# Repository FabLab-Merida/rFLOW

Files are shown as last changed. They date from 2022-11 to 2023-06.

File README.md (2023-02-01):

# rFLOW - FabLab Mérida

Proyecto made in FabLab Mérida por el cual mediante el reciclaje de una antigua plancha de vapor y algunos componentes electronicos, se ha convertido en una estación de soldadura BGA monocapa. Capaz de llegar hasta 250º, ideal para multiples tipos de pasta de estaño.

## Motivación  

La principal motivación tras este proyecto es buscar una solución económica a la creacion de PCBs y reparación de estas promoviendo la economia circular y el reciclaje de componentes y piezas.

## Materiales 

1 * Relé de 5V que soporte como miínimo 250V y 13A. <br />
1 * Termistor (vease el .ino para mas información). <br />
1 * Resistencia de la plancha de vapor. <br />
1 * Baquelita monocapa virgen. <br />
1 * ATMEGA 328p. <br />
3 * Botones Push. <br />
3 * Resistencias de 1kO. <br />
1 * Resistencia de 4.7kO. <br />
1 * Condensador de 10uF. <br />
1 * Potenciometro 10kO. <br />
1 * LCD 16*4 segmentos. <br />

## Resultados

La posibilidad de usar un amplio rango de temperatura estable ha dado lugar a múltiples aplicaciones extra, desde el anteriormente mencionada creación de PCBs pasando por facilitar soldaduras por aire manteniendo la zona caliente o secado de filamento de impresora 3D.

## Observaciones

Se necesita que el Atmega use la frecuencia de relog interna de 8MHz, para ello se necesita grabar el bootloader por uno sin los parametros de Arduino, en la bibliografía encontrará información de como hacerlo.

## Bibliografía

LiquidCrystal.h          ==> https://www.arduino.cc/reference/en/libraries/liquidcrystal/ <br />
thermistor.h             ==> https://github.com/miguel5612/ThermistorLibrary <br />
Grabar bootloader        ==> https://docs.arduino.cc/built-in-examples/arduino-isp/ArduinoToBreadboard <br />

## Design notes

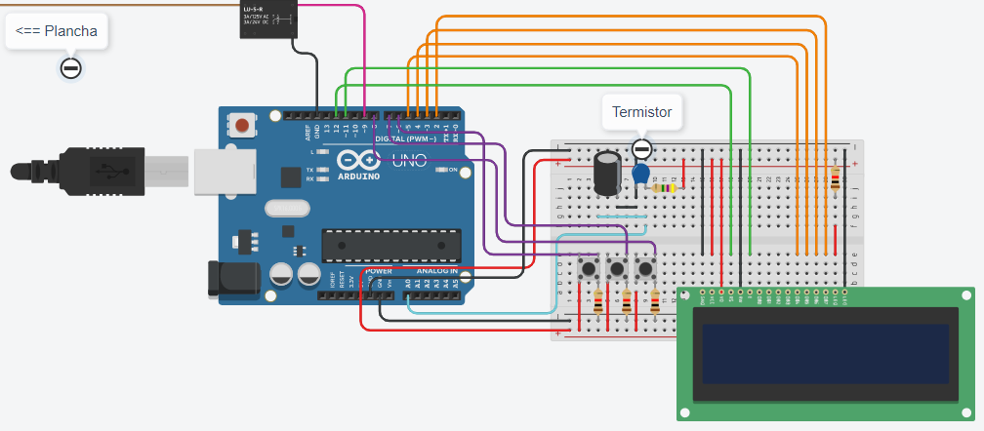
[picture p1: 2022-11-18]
Diagrama.png

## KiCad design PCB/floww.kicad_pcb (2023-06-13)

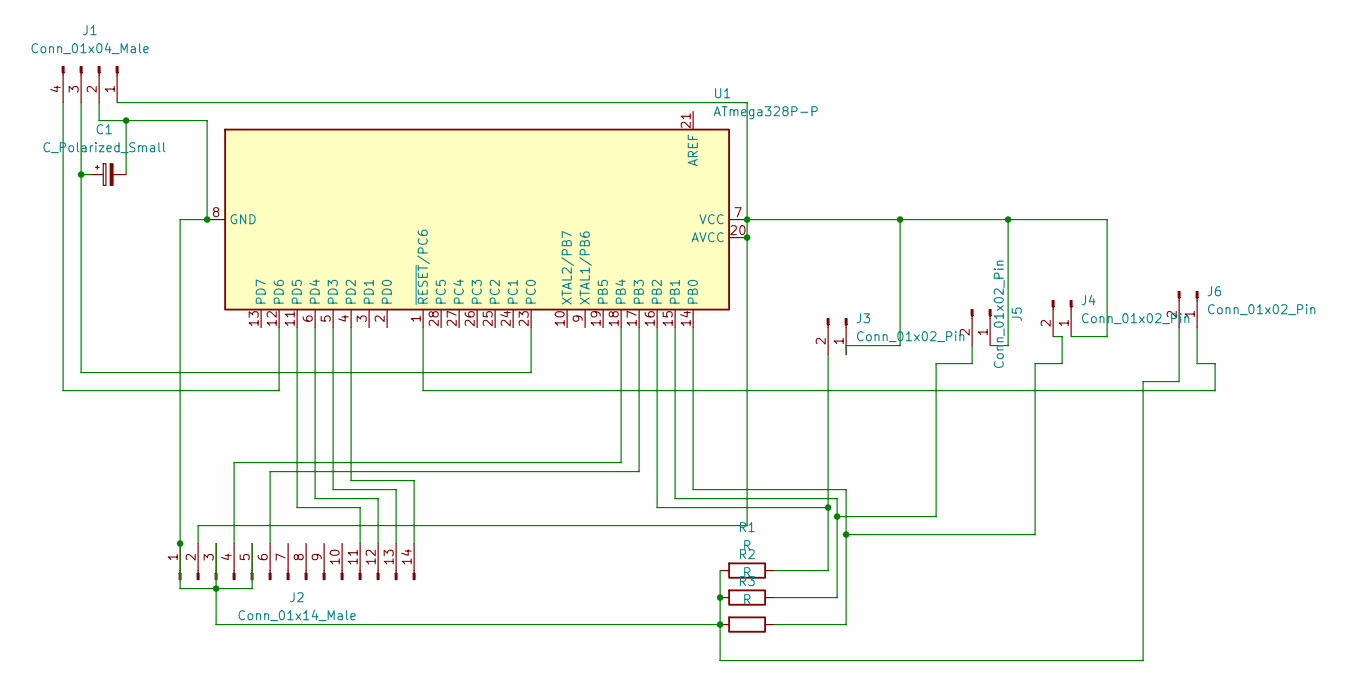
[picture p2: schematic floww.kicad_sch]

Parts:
C1: C_Polarized_Small; CP_Radial_D5.0mm_P2.50mm
J1: Conn_01x04_Male; PinHeader_1x04_P2.54mm_Vertical
J2: Conn_01x14_Male; PinHeader_1x14_P2.54mm_Vertical
J3, J4, J5, J6: Conn_01x02_Pin; PinHeader_1x02_P2.54mm_Vertical
R1, R2, R3: R; R_Axial_DIN0207_L6.3mm_D2.5mm_P10.16mm_Horizontal
U1: ATmega328P-P; DIP-28_W7.62mm

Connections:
unnamed: J1.1, J2.2, J3.1, J4.1, J5.1, U1.7 (VCC), U1.20 (AVCC)
unnamed: C1.2, J1.2, J2.1, J2.3, J2.5, J6.2, R1.2, R2.2, R3.2, U1.8 (GND), U1.22 (GND)
unnamed: C1.1, J1.3, U1.23 (PC0)
unnamed: J1.4, U1.12 (PD6)
unnamed: J2.4, U1.18 (PB4)
unnamed: J2.6, U1.17 (PB3)
unnamed: J2.11, U1.11 (PD5)
unnamed: J2.12, U1.6 (PD4)
unnamed: J2.13, U1.5 (PD3)
unnamed: J2.14, U1.4 (PD2)
unnamed: J3.2, R1.1, U1.16 (PB2)
unnamed: J4.2, R3.1, U1.14 (PB0)
unnamed: J5.2, R2.1, U1.15 (PB1)
unnamed: J6.1, U1.1 (~RESET/PC6)

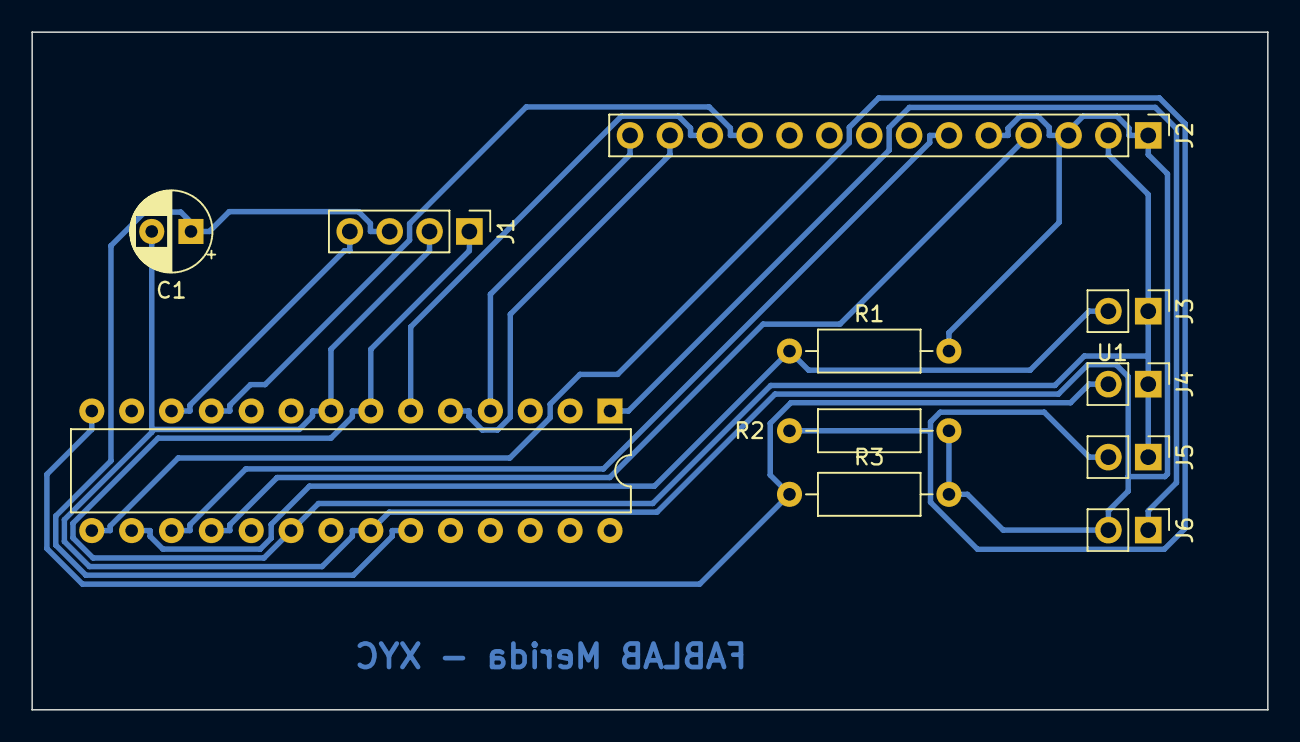
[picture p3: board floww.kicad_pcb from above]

Board: 2 copper layers, 78.7 x 43.2 mm, 11 parts (0 on the bottom side), 14 nets.

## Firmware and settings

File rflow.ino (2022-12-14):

/* ****************************************************
 * ****                                           *****
 * ****  ESTACIÓN DE SOLDADURA BGA Y REFLOW       *****
 * ****  VER: 1A   -   by CyX - FabLab Mérida     *****
 * ****                                           *****
 * ****************************************************/


#include <LiquidCrystal.h>  //https://www.arduino.cc/reference/en/libraries/liquidcrystal/
#include <thermistor.h>     //https://github.com/miguel5612/ThermistorLibrary


// ##### Variables de configuración ####

//Configuración de hardware
int tipo_termistor = 1;  //https://github.com/miguel5612/ThermistorLibrary#supported-thermistors
int tasa_temp = 3;      // Grados de "caché" para que el estaño se funda

//Configuración de los pines

int pin_boton_mas = 8;
int pin_boton_menos = 10;
int pin_boton_ok = 9;
int pin_plancha = 6;
int pin_termistor = A0;

const int rs = 12, e = 11, d4 = 5, d5 = 4, d6 = 3, d7 = 2;  //Pines de la pantalla

// Estáticas
int temp_min = 60;
int temp_max = 210;
int temp_act = temp_min;

// ##### Variables del programa ####
bool inicializado = false;
int temp;
thermistor tempe(pin_termistor, tipo_termistor);
LiquidCrystal lcd(rs, e, d4, d5, d6, d7);

// ##### Funciones del programa ####

bool inicializacion();
void calentar();
int tomar_temp();  // Candidata a irse

void setup() {
  lcd.begin(16, 4);
  pinMode(pin_plancha, OUTPUT);
  pinMode(pin_termistor, INPUT);
  pinMode(pin_boton_ok, INPUT);
  pinMode(pin_boton_mas, INPUT);
  pinMode(pin_boton_menos, INPUT);
}

void loop() {
  lcd.setCursor(3, 1);
  lcd.print("Project rFLOW");
  lcd.setCursor(5,2);
  lcd.print("Cy - FABLAB Merida");
  delay(2000);
  inicializado = inicializacion();
  calentar();
  while (tomar_temp() + tasa_temp > temp_act) {
    lcd.clear();
    lcd.print("Temperatura: ");
    lcd.print(tomar_temp());
    delay(500);
  }
}

bool inicializacion() {

  while (inicializado != true) {
    lcd.clear();
    lcd.print("Temp. incial: ");
    lcd.print(temp_act);
    if (digitalRead(pin_boton_mas) == HIGH && temp_act >= temp_min && digitalRead(pin_boton_mas) == HIGH && temp_act < temp_max) {
      temp_act += 10;
    }
    if (digitalRead(pin_boton_menos) == HIGH && temp_act > temp_min && digitalRead(pin_boton_menos) == HIGH && temp_act <= temp_max) {
      temp_act -= 10;
    }
    if (digitalRead(pin_boton_ok) == HIGH) {
      return true;
    }
    delay(100);
  }
}


int tomar_temp() {  //Funcion optimizable (y eliminable), pero pereza
  temp = tempe.analog2temp();
  return temp;
}


void calentar() {
  if (tomar_temp() < temp_act) {
    while (tomar_temp() < temp_act) {
      digitalWrite(pin_plancha, 1);
      //Control de temperatura
      lcd.clear();
      lcd.print("Calentando,espere...");
      lcd.setCursor(0, 1);
      lcd.print("Temperatura: ");
      lcd.print(tomar_temp());
      lcd.print("/");
      lcd.print(temp_act);
      delay(300);
    }
  }

  if (tomar_temp() >= temp_act) {
    digitalWrite(pin_plancha, LOW);
  }
}
